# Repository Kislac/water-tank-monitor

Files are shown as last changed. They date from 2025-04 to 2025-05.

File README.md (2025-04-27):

# LiDAR Water Tank Monitor

## Overview

The LiDAR Water Tank Monitor is an ESP32-based (Sunton esp32-2432S032C) project designed to measure and monitor water levels in a tank using a LiDAR sensor. The system integrates with **Home Assistant** via MQTT, providing real-time data on water levels, temperature, and humidity. It features a 3.2-inch capacitive TFT display with LVGL for a user-friendly interface.

The sensor and ESP32 board are connected using an S/FTP Ethernet cable (up to 10 meters), which ensures reliable communication and power delivery over longer distances. This setup helps minimize interference and signal loss, making it suitable for installations where the tank and display/controller are physically separated.

## Table of Contents

- [LiDAR Water Tank Monitor](#lidar-water-tank-monitor)
  - [Overview](#overview)
  - [Table of Contents](#table-of-contents)
  - [Key Features](#key-features)
    - [Main Features](#main-features)
    - [Home Assistant Integration Example](#home-assistant-integration-example)
    - [Hardware](#hardware)
    - [Software](#software)
    - [Customizable Settings](#customizable-settings)
  - [How its Work](#how-its-work)
  - [Development Environment Setup Instructions](#development-environment-setup-instructions)
  - [Pictures](#pictures)
    - [SquareLine Studio Settings](#squareline-studio-settings)
  - [Recommended Wiring Example](#recommended-wiring-example)
  - [Example Circuit](#example-circuit)
  - [T568B Pinout](#t568b-pinout)
  - [Bill of Materials (BOM)](#bill-of-materials-bom)
  - [Sunton esp32-2432S032C Description](#sunton-esp32-2432s032c-description)
  - [Purchase Links](#purchase-links)

## Key Features

### Main Features

- Real-time water level graph visualization
- Temperature and humidity display visualization
- RSSI Visualization
- **WiFi Management:** Scan/connect, display signal strength
- **Backlight Control:** Manual/automatic brightness
- **NTP Time Sync:** Synchronize with NTP servers
- **EEPROM Storage:** MQTT credentials, tank parameters, Wifi
- **MQTT Discovery:** Auto-publish sensor data to Home Assistant
  - Distance (mm)
  - Humidity (%)
  - Liter (L)
  - TankLevelTankLevel (%)
  - Temperature (°C)
- **Misc:**:
  - Dark Mode
  - Languge settings
  - Rotate Screen horizontaly (180°)
  - SW reset Button
  - Runtime Calc
  - FW update Over the AIR

  ### Home Assistant Integration Example

  <p align="center">
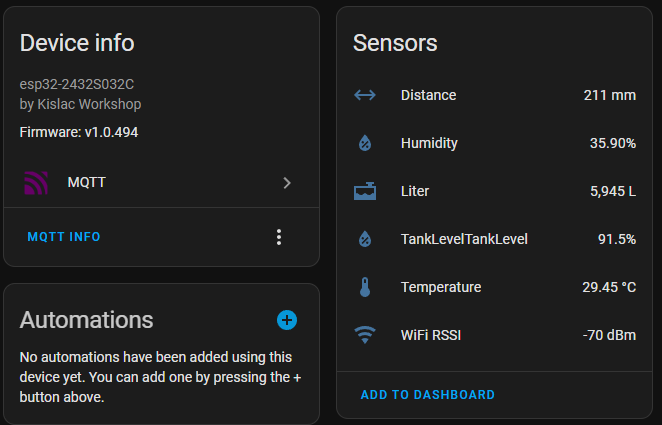
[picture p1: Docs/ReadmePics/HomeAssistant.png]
Home Assistant Integration Example
    
  </p>

### Hardware
- Main HW: Sunton esp32-2432S032C
  - **Microcontroller:** ESP32-D0WDQ6 (Dual-core, 240 MHz, 4 MB SPI Flash)
  - **Display:** 3.2-inch TFT LCD (320x240, 65K colors)
  - **Touchscreen:** GT911 capacitive touch controller (I2C)
  - **Audio:** PWM audio output with built-in amplifier
  - **Connectivity:** WiFi 802.11 b/g/n, Bluetooth v4.2 + BLE
  - **Power Supply:** 5V via USB Type-C, built-in LiPo charging IC
  - **GPIO:** Limited (many pins used for peripherals)
  - **LED:** RGB Led
  - **LightSensor:** used for auto backlight
- **Sensors:**
  - **LiDAR**: TOF400C-VL53L1X
  - **Temperature & Humidity**: AHT10

### Software

- **Framework:** VSCode: Arduino with PlatformIO
- **Libdeps**: 
	- https://github.com/rzeldent/esp32-smartdisplay
	- lvgl/lvgl@^9.2.2
	- knolleary/PubSubClient@^2.8
	- adafruit/Adafruit AHTX0@^2.0.5
	- pololu/VL53L1X@^1.3.1
	- bblanchon/ArduinoJson@^7.4.1
- **UI Library:** LVGL (v9.1.0)
- **Integration:** MQTT for Home Assistant
- **OTA Updates:** Firmware updates via HTTPS
- **PCB Design:** Sprint Layout 6.0
- **CNC File Preparation:** FlatCam
- **PCB Engraving:** UGS 2.1.13 (Universal Gcode Sender)
- **MQTT Testing:** MQTT Explorer 0.4

### Customizable Settings

- Tank type (cylinder or rectangle)
- Tank dimensions and calibration

---

## How its Work

>The system uses a distance sensor mounted above the water tank. The sensor continuously measures the distance from itself to the water surface. Using the tank's dimensions (such as height and diameter), the software calculates the current water level and the total volume of water remaining in the tank. This information is displayed in real time on the screen. Additionally, the system sends water level data via MQTT to Home Assistant for remote monitoring and automation.
---
<p align="center">
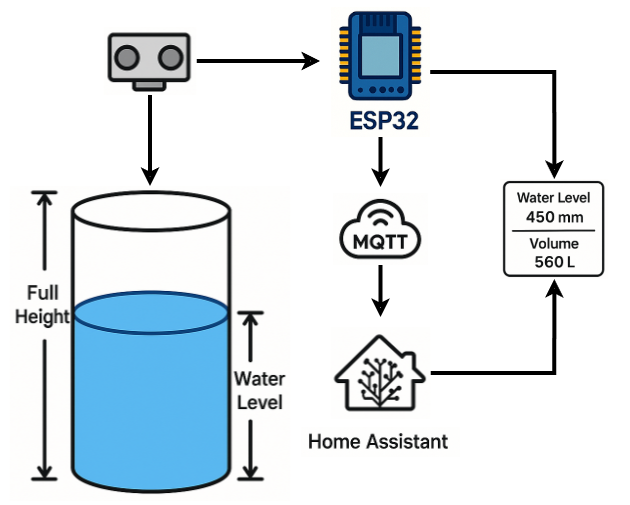
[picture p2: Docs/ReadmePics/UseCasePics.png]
    
  </p>

## Development Environment Setup Instructions
*Only need if you wold like to modify something

1. **Follow these steps:**  
  [https://github.com/rzeldent/esp32-smartdisplay](https://github.com/rzeldent/esp32-smartdisplay)

2. **Install SquareLine Studio:**  
  Version: `SquareLine_Studio_Windows_v1_4_2`

3. **Clone the PlatformIO board definitions:**  
  - Repository: [https://github.com/rzeldent/platformio-espressif32-sunton](https://github.com/rzeldent/platformio-espressif32-sunton)
  - Copy the board definitions to:  
    `<home>/.platformio/platforms/espressif32/boards`
  - 
4. **Create new projects**
  - use the `esp32-2432S032C` board and Aurdiono 
  - Copy  `\.pio\libdeps\esp32-2432S032C\lvgl\lv_conf_template.h`  
  to `\include` and rename to `lv_conf.h` and enable it with `#if 1`
- Provide LVGL config path in `pf.ini` with:  
  `-D LV_CONF_PATH="D:\GIT\water-tank-monitor\include\lv_conf.h"`
- Add `lvgl/lvgl@^9.2.2` library to the project

5. **Memory Map update**
LVGL are using too much Dram. So need to modify the Dram mapping
Find this file
`C:\Users\ikl2bp\.platformio\packages\framework-arduinoespressif32\tools\sdk\esp32\ld\memory.ld`:
Update this part to this:
>dram0_0_seg (RW) : org = 0x3FFB0000 + 0xdb5c,<br>
             len = 0x32710 - 0xdb5c

*Explanation:*
- Start address: `0x3FFB0000`
- Offset: `0xdb5c` (56,796 decimal)
- Total length: `0x30000` (196,608 decimal)
- Available memory: `0x30000 - 0xdb5c = 0x224A4` (140,812 decimal)

---
## Pictures

<p align="center">
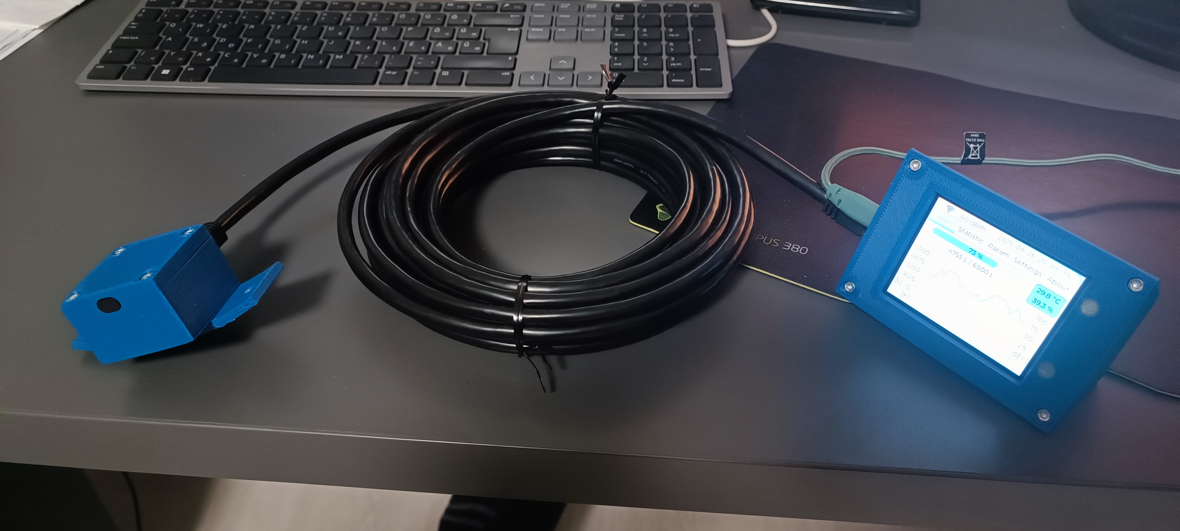
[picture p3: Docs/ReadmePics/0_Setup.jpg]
Device Setup
  
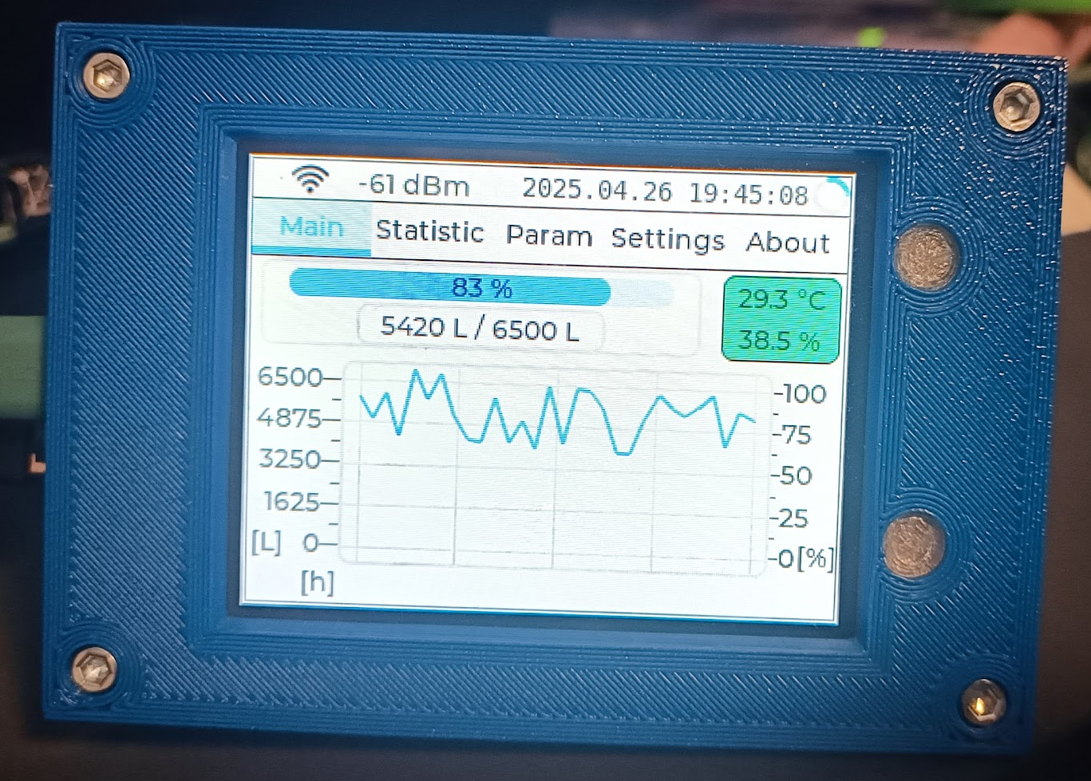
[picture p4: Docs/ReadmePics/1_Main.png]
Main Screen
  
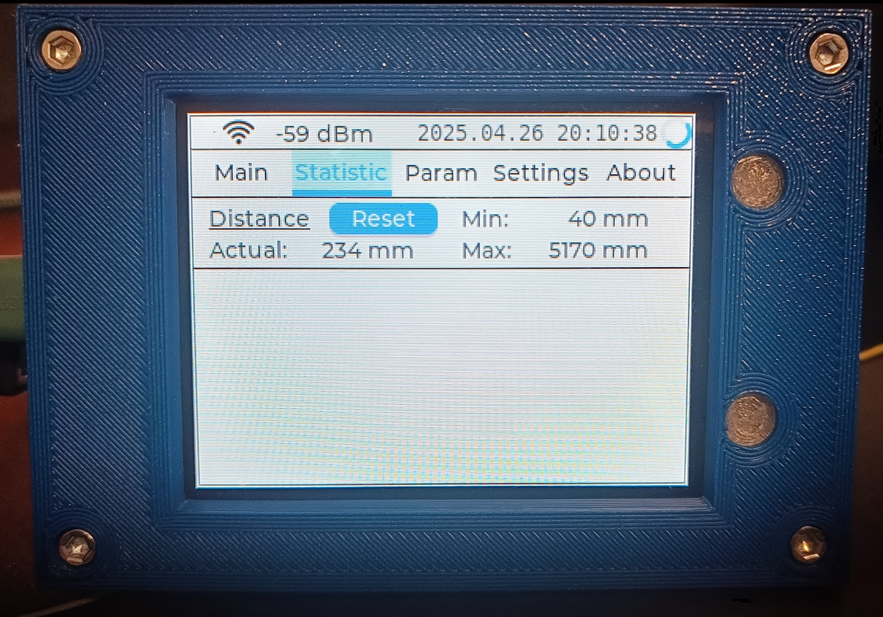
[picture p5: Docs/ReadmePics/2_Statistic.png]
Statistics Screen
  
  Parameter Screen
  Settings Screen
  About Screen
</p>

---

## SquareLine Studio Settings

- **New Project:**
  - Major LVGL version: 9.1
  - Visual Studio for development on Windows PC (v2.0.1)
  - Resolution: 320x240
  - Color Depth: 16 Bit
  - LVGL version: 9.1.0
  - Project Export Root: `D:\GIT\water-tank-monitor`
  - UI Files Export Path: `D:\GIT\water-tank-monitor\src\ui`
  - LVGL Include Path: `lvgl.h`
  - Call functions export file: *do not export*

---

## Recommended Wiring Example

| Pair | Color | Signal |
|---|---|---|
| 1 | Green + Green/White  | SDA + GND |
| 2 | Orange + Orange/White| SCL + GND |
| 3 | Blue + Blue/White | +5V + empty |
| 4 | Brown + Brown/White  | Optional: LED or GPIO |

- Use a lower I2C speed (e.g., 100kHz)
- Use stronger pull-up resistors (e.g., 1.5kΩ instead of 2.2kΩ)
- According to the I2C specification, pull-up resistors are required on SDA and SCL lines.

| Length | Voltage | Recommended Pull-up |
|---|---|---|
| < 1 m  | 3.3V | 4.7kΩ – 10kΩ |
| 5–6 m  | 3.3V | 2.2kΩ – 3.3kΩ |

---

## Example Circuit

```text
ESP32
  ├── SDA ---[2.2kΩ]---+--- SDA wire ---> VL53L1X & AHT10
  │                   |
  │                  3.3V
  └── SCL ---[2.2kΩ]---+--- SCL wire ---> VL53L1X & AHT10

VL53L1X & AHT10
  └── 3.3V ---||--- GND (100nF + 10µF in parallel)
```

---

## T568B Pinout

1. Orange/White    → GND  
2. Orange          → SCL  
3. Green/White     → GND  
4. Blue            → +5V  
5. Blue/White      → Empty  
6. Green           → SDA  
7. Brown/White     → Empty  
8. Brown           → Empty  

---

## Bill of Materials (BOM)
|Picture|Item|Needed|Price(EUR)|Price (HUF)|AliExpress Link| Hungarian Distributor Link|
|-|-|-|-|-|-|-|
|TOF400C-VL53L1|Sunton<br> esp32-2432S032C|1|20 eur|8500 huf|[AliExpress](https://www.aliexpress.com/item/1005008599170226.html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"order"%3A"2"%2C"eval"%3A"1"%7D&pdp_npi=4%40dis%21HUF%218710.51%218276.09%21%21%2123.66%2122.48%21%402103917f17456769168285149e6771%2112000045892717254%21sea%21HU%21165456939%21X&curPageLogUid=LtDidy4eRF31&utparam-url=scene%3Asearch%7Cquery_from%3A)|[Tavir](https://shop.tavir.hu/termek/kiegeszitok/kommunikacio/esp32-lvgl-development-board-3-2-lvgl-touch-esp32-2432s032c/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)|
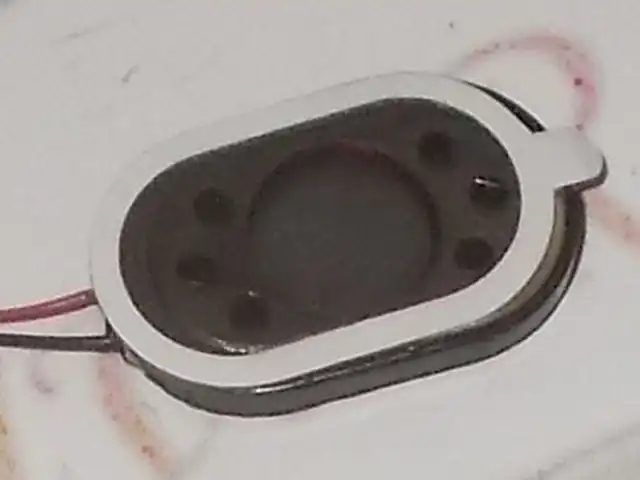
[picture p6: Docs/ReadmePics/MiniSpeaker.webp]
||MiniSpeaker <br>(8R 1W)<br> (Optionally)|1|1 eur|400 huf|[AliExpress](https://www.aliexpress.com/item/1005006116555207.html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"order"%3A"178"%2C"eval"%3A"1"%7D&pdp_npi=4%40dis%21HUF%21921.25%21792.09%21%21%2118.26%2115.70%21%4021038e6617456773259747782e78fa%2112000035824265950%21sea%21HU%21165456939%21X&curPageLogUid=WIlYI5tJOtuN&utparam-url=scene%3Asearch%7Cquery_from%3A)|[Tavir](https://shop.tavir.hu/termek/modulok/hangkeltes-mp3-erosito/mini-hangszoro-8r-1w/)|
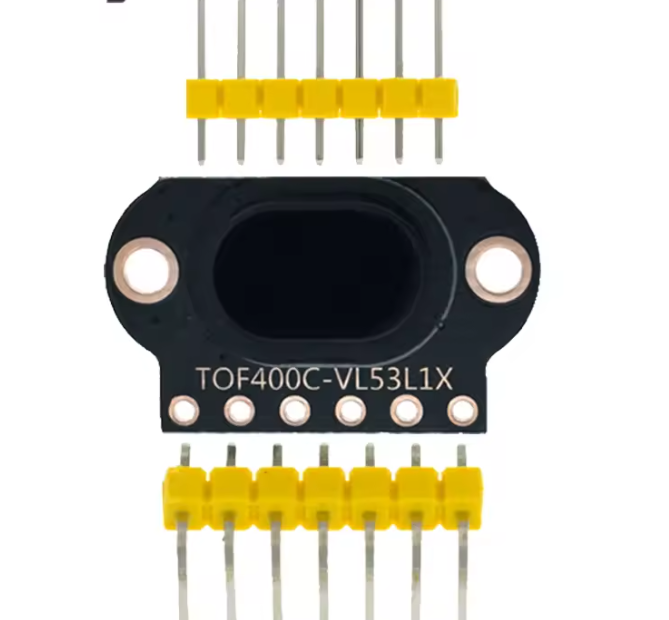
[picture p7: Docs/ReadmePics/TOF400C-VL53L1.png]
||TOF400C-VL53L1|1 pcs|5 eur|2000 huf| [AliExpress](https://www.aliexpress.com/item/1005006160743016.html?spm=a2g0o.order_list.order_list_main.10.6d311802U5VZOT)| [Hestore](https://www.hestore.hu/prod_10041187.html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)|
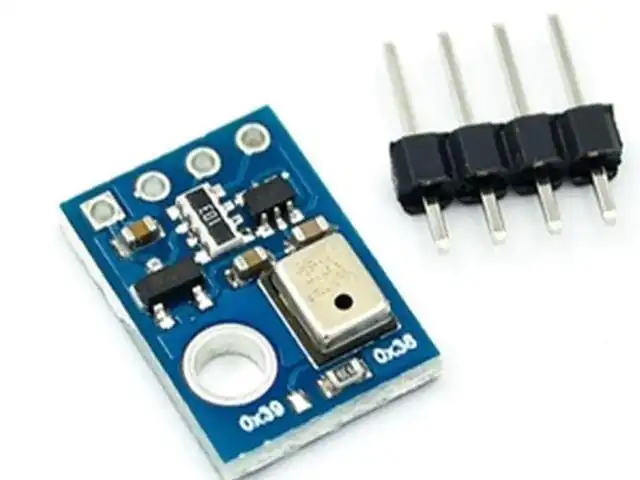
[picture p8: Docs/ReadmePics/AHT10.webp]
||AHT10|1 pcs|2.5 eur|1000 huf|[AliExpress](https://www.aliexpress.com/item/1005005023375532.html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)|[Tavir](https://shop.tavir.hu/termek/modulok/homerseklet/aht10-ho-paraszenzor/)|
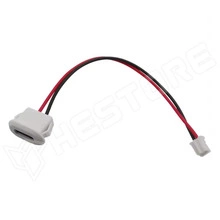
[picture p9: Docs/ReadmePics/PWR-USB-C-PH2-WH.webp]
||PWR-USB-C-PH2-WH|1pcs|? eur|? huf|-|[Hestore](https://www.hestore.hu/prod_10047569.html)|
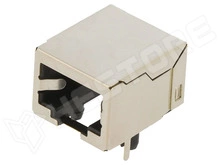
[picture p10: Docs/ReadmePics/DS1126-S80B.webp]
DS1126-S80B
||DS1126-S80B <br>(or similiar)|2pcs|1 Eur|400 Huf|-|[Hestore](https://www.hestore.hu/prod_10041015.html)|
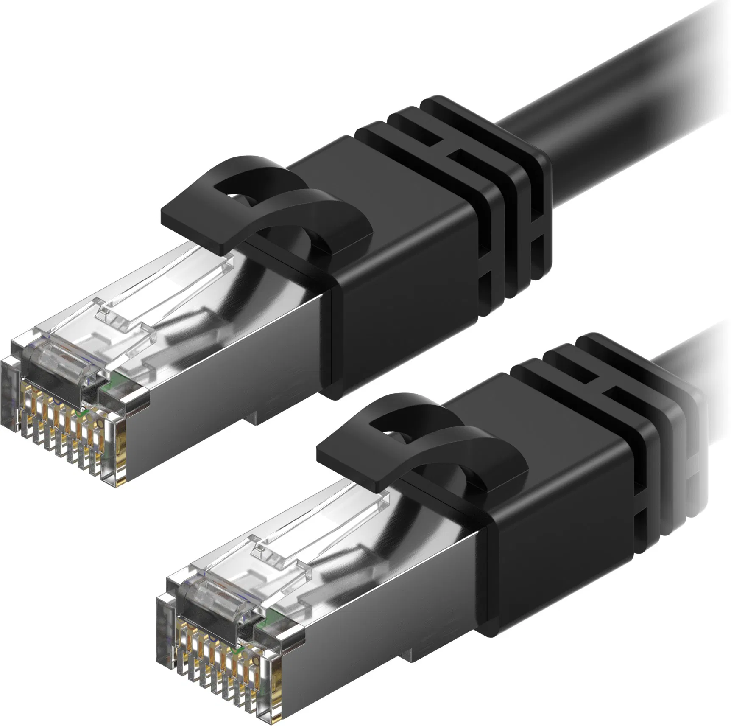
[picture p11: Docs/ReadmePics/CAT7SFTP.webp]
||S/FTP|1pcs|14 Eur|5500 Huf|-|[Alza](https://www.alza.hu/alzapower-patch-cat7-s-ftp-30m-sedy?dq=12481409)|
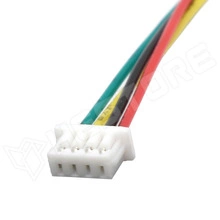
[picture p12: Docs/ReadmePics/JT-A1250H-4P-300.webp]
JT-A1250H-4P-300
||JT-A1250H-4P-300|2pcs|1 eur|500 Huf|-|[Hestore](https://www.hestore.hu/prod_10047751.html)|
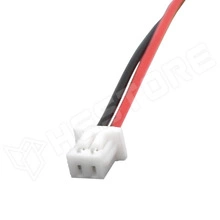
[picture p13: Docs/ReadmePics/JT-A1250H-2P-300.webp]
JT-A1250H-2P-300
||JT-A1250H-4P-300|2pcs|1 eur|500 Huf|-|[Hestore](https://www.hestore.hu/prod_10047749.html)|
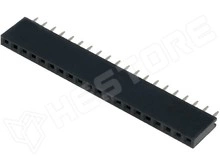
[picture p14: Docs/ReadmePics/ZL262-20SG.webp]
ZL262-20SG
||ZL262-20SG|2 pcs|1 eur|400 Huf|-|[Hestore](https://www.hestore.hu/prod_10028051.html)|
|Total|-|-|~47 Eur|~19200 Huf||-|

---

## Sunton esp32-2432S032C Description

## Purchase Links

- **OEM Product Page:**  
  [displaysmodule.com - 3.2" Capacitive TFT Display Module (240x320, ESP32, LVGL, SPI)](https://www.displaysmodule.com/sale-36526879-capacitive-3-2-inch-tft-display-module-240x320-esp32-lvgl-spi-lcd-module.html)

- **Sunton Official AliExpress Store:**  
  [AliExpress Store #1102010846](https://www.aliexpress.com/store/1102010846)

- **Example AliExpress Listing:**  
  [ESP32-2432S032C Board - AliExpress](https://www.aliexpress.com/item/1005007053922331.html)

- **Hungarian Distributor:**  
  [Tavir.hu - ESP32 LVGL Development Board 3.2"](https://shop.tavir.hu/termek/kiegeszitok/kommunikacio/esp32-lvgl-development-board-3-2-lvgl-touch-esp32-2432s032c/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)

**Main Features:**

- **Microcontroller:**  
  ESP32-D0WDQ6 (Dual-core, 240 MHz)

- **RAM:**  
  520 KB internal SRAM  
  *No separate PSRAM on this board*

- **ROM:**  
  448 KB

- **Flash Memory:**  
  4 MB SPI Flash (for programming and data storage)

- **Display:**  
  3.2 inch, 320x240 pixel, 65K color, TFT-LCD  
  ST7789 controller (SPI interface)  
  GT911 capacitive touch controller (I2C interface)

- **Touchscreen Connection:**  
  I2C bus (default: IO32 - SDA, IO33 - SCL)

- **Audio:**  
  PWM audio output: GPIO26 (amplified, via PicoBlade connector)  
  Built-in amplifier

- **Other Peripherals:**  
  RGB LED  
  Light sensor (generally not functional)  
  SD card slot (SPI)

- **Communication:**  
  WiFi 802.11 b/g/n  
  Bluetooth v4.2 + BLE

- **Power Supply:**  
  5V via USB (Type-C)  
  Built-in LiPo battery charging IC (*does not support deep sleep!*)

- **GPIO Connectors:**  
  Limited availability, as many pins are fixed for display, touch panel, audio output, etc.

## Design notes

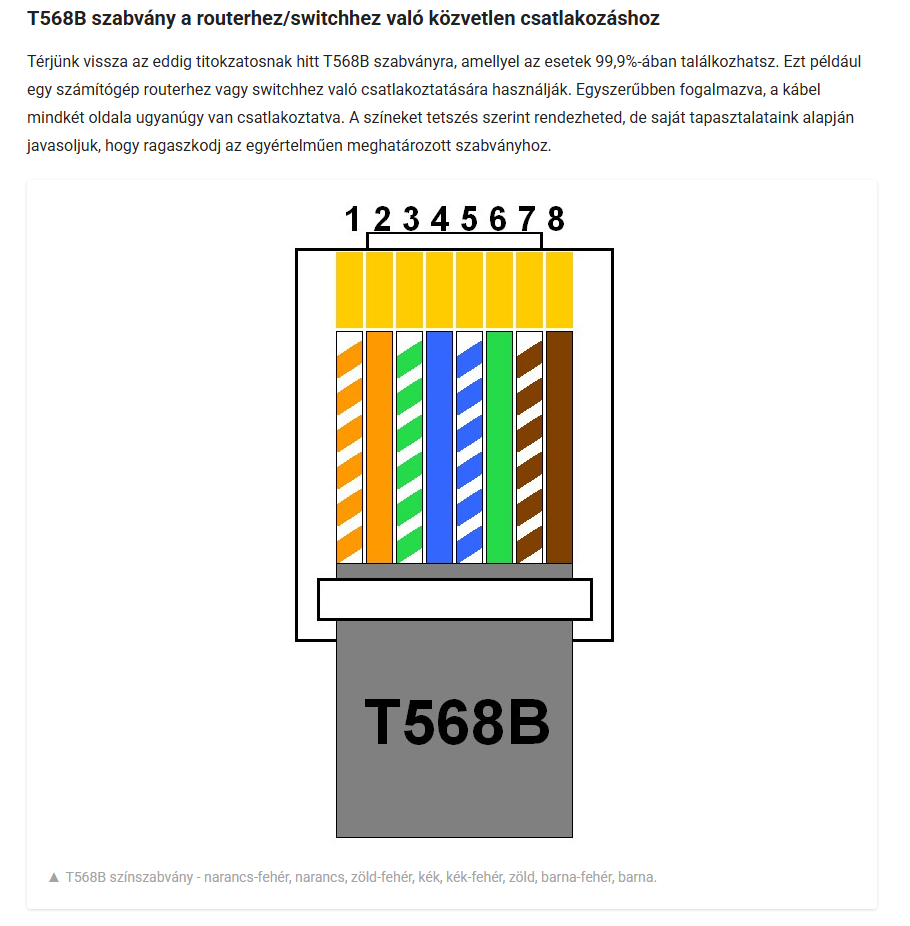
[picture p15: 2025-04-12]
Docs/2025-04-12_16h45_10.png

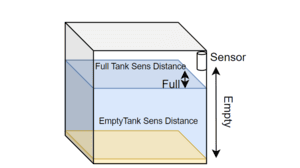
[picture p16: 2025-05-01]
Docs/Resized/4_TankFullEmpty.png

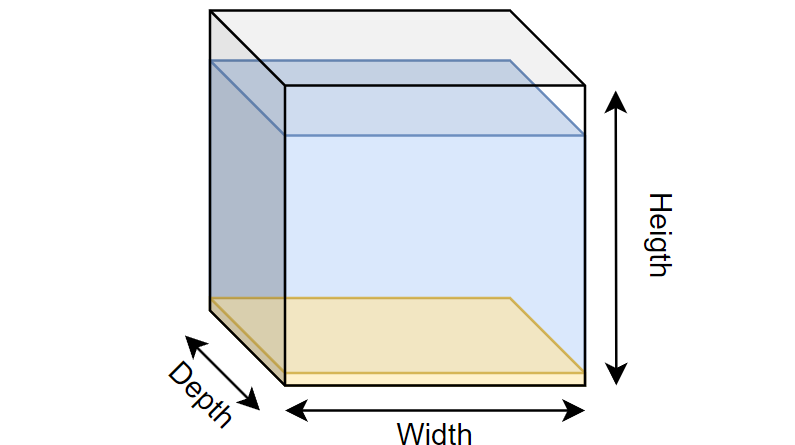
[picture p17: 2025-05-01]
Docs/2_ReactangleDimensions.png

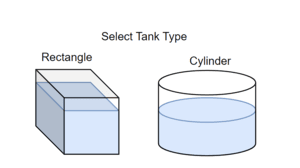
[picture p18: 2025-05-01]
SquareLine/assets/1_SelectTankType.png

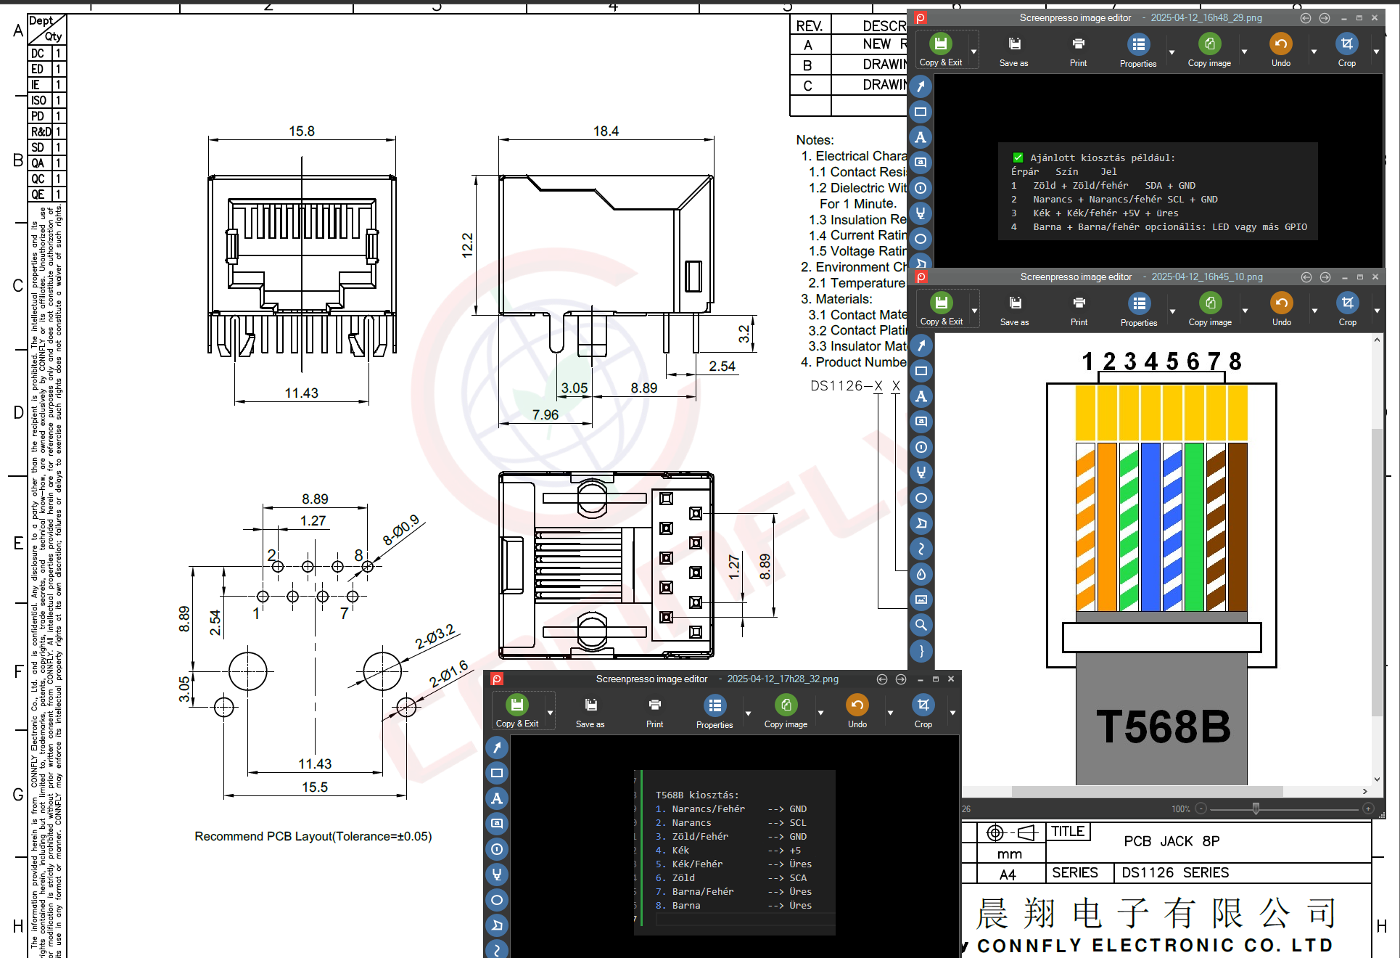
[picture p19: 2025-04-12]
Docs/2025-04-12_17h29_19.png

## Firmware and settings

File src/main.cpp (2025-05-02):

#include "globals.h"
#include <Arduino.h>
#include <esp32_smartdisplay.h>
#include <ui/ui.h>
#include <WiFi.h>
#include <FS.h>     // Include the SPIFFS library for Version handling
#include <SPIFFS.h> // Include the SPIFFS library for Version handling
#include <PubSubClient.h>
#include <EEPROM.h>
//#include <esp_heap_caps.h>

//include OTA
#include <HTTPClient.h>
#include <ArduinoJson.h>
#include <HTTPUpdate.h>



//-------------------------------
#include <Wire.h>
#include <Adafruit_AHTX0.h>
// Define I2C pins for AHT10 (IO21 for SDA, IO22 for SCL)
#define AHT10_SDA 21
#define AHT10_SCL 22

// Define I2C pins for VL53L1X (IO21 for SDA, IO22 for SCL)
#define VL53L1X_SDA 21
#define VL53L1X_SCL 22

// Create a TwoWire object for I2C_NUM_1
TwoWire I2C_AHT10 = TwoWire(1);  // Specify the I2C peripheral (1 for I2C_NUM_1)

Adafruit_AHTX0 aht = Adafruit_AHTX0();  // Create the sensor object
float Temperature_Value = 0;
float Huminidity_Value = 0;


TwoWire I2C_VL53L1X = TwoWire(1);  // Specify the I2C peripheral (1 for I2C_NUM_1)
#include <VL53L1X.h>
VL53L1X sensor;// = VL53L1X();
// Define arrays to store temperature and humidity data
float temp_data[10] = {0};
float hum_data[10] = {0};
int data_index = 0;
//------------------------
bool lvgl_enabled = true;

bool vl53l1x_initialized = false;
bool aht10_initialized = false;


//Set the screen brightness to 50% initially
#define SCREEN_INITIAL_BRIGHTNESS 50
ulong next_millis;
auto lv_last_tick = millis();
char text_buffer[32];

int64_t now = 0;
String security;

bool internetOK = false;
bool wifiConnected = false;
char macAddress[18];
char device_name[32];
char device_identifiers[32];
char device_manufacturer[32];
char device_model[32];
char device_sw_version[32];

WiFiClient espClient;
PubSubClient client(espClient);
bool MQTT_Configured = false;

char global_mqtt_server[64];
char global_mqtt_user[64];
char global_mqtt_password[64];

bool FW_Update_Check = false;


int global_minDistance = INT_MAX; // Initialize to maximum possible value
int global_maxDistance = INT_MIN; // Initialize to minimum possible value

int build_number = 0;

uint8_t global_tankType = 0;
uint16_t global_rectWide = 0;
uint16_t global_rectDepth = 0;
uint16_t global_rectHeight = 0;
uint16_t global_cilDiameter = 0;
uint16_t global_cilHeight = 0;
uint16_t global_emptyTank = 0;
uint16_t global_fullTank = 0;
float global_MaxTankLevelInLiter = 0;
float global_tankVolume = 0.0f;

int distance = 0;
int CurrentLiter;
float CurrentLiterInPer;

// Inicializáld a globális változót
//lv_obj_t * global_ui_Info = NULL;

void initializeBuildInfo()
{
  
  // Get and print the build date and time
  Serial.printf("Build Date: %s, Build Time: %s\n", __DATE__, __TIME__);

  // Update the ui_BuildDateValue with the build date and time
  lv_label_set_text_fmt(ui_lblBuildDateValue, "%s %s", __DATE__, __TIME__);
  
  // Read the build number from version.txt
  if (!SPIFFS.begin(true)) {
    Serial.println("An Error has occurred while mounting SPIFFS");
    return;
  }

  File versionFile = SPIFFS.open("/version.txt", "r");
  if (!versionFile) {
    Serial.println("Failed to open version file");
    return;
  }

  build_number = versionFile.parseInt();
  Serial.printf("Build_number: %d \n", build_number);
  versionFile.close();

  // Update the ui_VerValue with the code version
  device_sw_version[16];
  sprintf(device_sw_version, "v1.1.%d", build_number);
  lv_label_set_text(ui_lblBuildVersionValue, device_sw_version);
}


lv_obj_t * WifiInternetOKImages[1];
lv_obj_t * WifiDisconnectedImages[1];
lv_obj_t * WifiConnectedNoInternetImages[1];
void initWifiSignalImages(){
  WifiInternetOKImages[0] = ui_imWifiInternetOK1;
  //WifiInternetOKImages[1] = ui_imWifiInternetOK2;
  //WifiInternetOKImages[2] = ui_imWifiInternetOK3;
  //WifiInternetOKImages[3] = ui_imWifiInternetOK4;
  //WifiInternetOKImages[4] = ui_imWifiInternetOK5;
  WifiDisconnectedImages[0] = ui_imWifiDisconnected1;
  //WifiDisconnectedImages[1] = ui_imWifiDisconnected2;
  //WifiDisconnectedImages[2] = ui_imWifiDisconnected3;
  //WifiDisconnectedImages[3] = ui_imWifiDisconnected4;
  //WifiDisconnectedImages[4] = ui_imWifiDisconnected5;
  WifiConnectedNoInternetImages[0] = ui_imWifiConnectedNoInternet1;
  //WifiConnectedNoInternetImages[1] = ui_imWifiConnectedNoInternet2;
  //WifiConnectedNoInternetImages[2] = ui_imWifiConnectedNoInternet3;
  //WifiConnectedNoInternetImages[3] = ui_imWifiConnectedNoInternet4;
  //WifiConnectedNoInternetImages[4] = ui_imWifiConnectedNoInternet5;
}


// Függvény a képek láthatóságának frissítésére
void updateStatusImages(bool internetOK) {
  // WiFi Disconnected képek kezelése

  int wifiDisconnectedImagesCount = sizeof(WifiInternetOKImages) / sizeof(WifiInternetOKImages[0]);
  //Serial.printf("wifiDisconnectedImages has %d elements\n", wifiDisconnectedImagesCount);
  for (int i = 0; i < wifiDisconnectedImagesCount; i++) {
    if (WifiInternetOKImages[i] == nullptr) {
      Serial.printf("wifiDisconnectedImages[%d] is nullptr\n", i);
    } else {
      //lv_obj_t* img = wifiDisconnectedImages[i];
      //if (img != nullptr) { // Ensure the pointer is not null
          if (wifiConnected && internetOK) {
              lv_obj_add_flag(WifiDisconnectedImages[i], LV_OBJ_FLAG_HIDDEN); // Elrejtés
              lv_obj_add_flag(WifiConnectedNoInternetImages[i], LV_OBJ_FLAG_HIDDEN); // Elrejtés
              lv_obj_clear_flag(WifiInternetOKImages[i], LV_OBJ_FLAG_HIDDEN); // Megjelenítés
          } else if (wifiConnected && !internetOK) {
              lv_obj_add_flag(WifiDisconnectedImages[i], LV_OBJ_FLAG_HIDDEN); // Elrejtés
              lv_obj_clear_flag(WifiConnectedNoInternetImages[i], LV_OBJ_FLAG_HIDDEN); // Megjelenítés
              lv_obj_add_flag(WifiInternetOKImages[i], LV_OBJ_FLAG_HIDDEN); // Elrejtés
          } else if (!wifiConnected){
              lv_obj_clear_flag(WifiDisconnectedImages[i], LV_OBJ_FLAG_HIDDEN); // Megjelenítés
              lv_obj_add_flag(WifiConnectedNoInternetImages[i], LV_OBJ_FLAG_HIDDEN); // Elrejtés
              lv_obj_add_flag(WifiInternetOKImages[i], LV_OBJ_FLAG_HIDDEN); // Elrejtés
          }  
    }
  }

}

// Hívás a státusz frissítésére
void CheckWifiandInternetStatus() {
    static ulong last_status_refresh_time = 0;

    if (millis() - last_status_refresh_time >= 1000) { // Refresh every second
      last_status_refresh_time = millis();

      wifiConnected = (WiFi.status() == WL_CONNECTED);
      internetOK = false;

      // Internet kapcsolat ellenőrzése
      WiFiClient client;
      if (wifiConnected && client.connect("www.google.com", 80)) {
        internetOK = true;
        client.stop();
      }

      // Frissítsd a képeket
      updateStatusImages(internetOK);
    }
}

void RefreshWifiParameters() {
  static ulong last_refresh_time = 0;

  if (millis() - last_refresh_time >= 5000) { // Refresh every 5 seconds
    last_refresh_time = millis();

    if(lv_scr_act() == ui_Wifi_Settings){
      // Refresh WiFi status
      const char *status = (WiFi.status() == WL_CONNECTED) ? "Connected" : "Disconnected";
      lv_label_set_text(ui_lblWifiStatus, status);


      if (WiFi.status() == WL_CONNECTED) {
        // Refresh SSID
        lv_label_set_text(ui_lblWifiSSID, WiFi.SSID().c_str());
        

        // Refresh IP address
        lv_label_set_text(ui_lblWifiIP, WiFi.localIP().toString().c_str());

        // Refresh RSSI
        char rssi_text[16];
        snprintf(rssi_text, sizeof(rssi_text), "%d dBm", WiFi.RSSI());
        lv_label_set_text(ui_lblWifiRSSI, rssi_text);
        //lv_label_set_text(ui_lblWifiRSSI2, rssi_text);

        // Refresh Channel
        char channel_text[16];
        snprintf(channel_text, sizeof(channel_text), "Ch: %d", WiFi.channel());
        lv_label_set_text(ui_lblWifiChannel, channel_text);

        lv_label_set_text(ui_lblWifiSecurity, security.c_str());

        
        
      } else {
        // Clear labels if not connected
        lv_label_set_text(ui_lblWifiSSID, "N/A");
        lv_label_set_text(ui_lblWifiRSSI2, "N/A");
        lv_label_set_text(ui_lblWifiIP, "N/A");
        lv_label_set_text(ui_lblWifiRSSI, "N/A");
        lv_label_set_text(ui_lblWifiChannel, "N/A");
        lv_label_set_text(ui_lblWifiSecurity, "N/A");
      }
    }else if(lv_scr_act() == ui_Main_Screen){
      if (WiFi.status() == WL_CONNECTED) {
        // Refresh RSSI
        char rssi_text[16];
        snprintf(rssi_text, sizeof(rssi_text), "%d dBm", WiFi.RSSI());
        lv_label_set_text(ui_lblWifiRSSI2, rssi_text);
      }else{
        lv_label_set_text(ui_lblWifiRSSI2, "- dBm");
      }
    }
  }
}

void runtimecalc(){
  static ulong last_runtime = 0;

  if (millis() - last_runtime >= 100) { // Refresh every 100ms
    last_runtime = millis();

    int64_t total_seconds = now / 1000;
    int years = total_seconds / (365 * 24 * 3600);
    total_seconds %= (365 * 24 * 3600);
    int days = total_seconds / (24 * 3600);
    total_seconds %= (24 * 3600);
    int hours = total_seconds / 3600;
    total_seconds %= 3600;
    int minutes = total_seconds / 60;
    float seconds = total_seconds % 60 + (now % 1000) / 1000.0;

    if (lv_tabview_get_tab_act(ui_MainTabView) == 4) {
        // Update the audio tab
        sprintf(text_buffer, "%02d-%03d %02d:%02d:%02.1f", years, days, hours, minutes, seconds);
        lv_label_set_text(ui_lblRunTimeValue, text_buffer);
        //sprintf(text_buffer, "%02d hour %02d min %02.1f sec", hours, minutes, seconds);
        //lv_label_set_text(ui_lblRuntimeHMSValue, text_buffer);
    }
  }
}

void DateAndTimeHandling(){
static ulong last_ntp_sync = 0;
static ulong last_time_update = 0;
static time_t current_time = 0; // Store the current time in seconds since epoch
//static int timezone_offset = 3600; // Default timezone offset in seconds (CET)

if (internetOK && (millis() - last_ntp_sync >= 60000*5 || current_time < 946684800)) { // Sync with NTP every 60 seconds or before year 2000
  configTzTime("CET-1CEST,M3.5.0/2,M10.5.0/3", "pool.ntp.org", "time.nist.gov"); // Configure NTP servers
  struct tm timeinfo;
  if (getLocalTime(&timeinfo)) {
    current_time = mktime(&timeinfo); // Update current time
    last_ntp_sync = millis();
    Serial.println("Time synchronized with NTP.");
  } else {
    Serial.println("Failed to synchronize time with NTP.");
  }
}

if (millis() - last_time_update >= 1000) { // Update time every second
  last_time_update = millis();
  current_time++; // Increment the current time by one second
  //Serial.printf("Current time: %d", current_time); // Print the current time
  struct tm *timeinfo = localtime(&current_time);
  if (timeinfo) {
    char datetime_text[32];
    strftime(datetime_text, sizeof(datetime_text), "%Y.%m.%d %H:%M:%S", timeinfo);
    //lv_label_set_text(ui_lblTime, datetime_text);
    lv_label_set_text(ui_lblDataNTime, datetime_text);

  } else {
    //lv_label_set_text(ui_lblTime, "Time Unavailable");
    lv_label_set_text(ui_lblDataNTime, "Time Unavailable");
  }
}
  
}

void AutoBacklight(){
  #ifdef BOARD_HAS_CDS
  static ulong last_AutoBacklight = 0;
  static int last_slider_value = 0;

  if (millis() - last_AutoBacklight >= 100) { // Refresh every 100ms
    // Debounced EEPROM save for slider value
    static ulong last_slider_change_time = 0;
    static bool slider_changed = false;

    last_AutoBacklight = millis();
    auto cdr = analogReadMilliVolts(CDS);
    sprintf(text_buffer, "%d", cdr);
    if (lv_tabview_get_tab_act(ui_MainTabView) == 3) {
        lv_label_set_text(ui_lblLigthSensorValue, text_buffer);
    }
    
    if (lv_obj_get_state(ui_switchManualAutomatic) & LV_STATE_CHECKED) {
        float adaptive_brightness = smartdisplay_lcd_adaptive_brightness_cds();
        smartdisplay_lcd_set_backlight(adaptive_brightness);
        if (lv_tabview_get_tab_act(ui_MainTabView) == 3) {
          int slider_value = (int)(adaptive_brightness * 100);
          lv_slider_set_value(ui_LigthSensorSlider, slider_value, LV_ANIM_OFF);
          sprintf(text_buffer, "%d%%", slider_value);
          lv_label_set_text(ui_lblLigthSensorSliderValue, text_buffer);
        }
    }
    int slider_value = lv_slider_get_value(ui_LigthSensorSlider);
    if (!(lv_obj_get_state(ui_switchManualAutomatic) & LV_STATE_CHECKED) && slider_value != last_slider_value) {
        // Read the slider value
        
        
        //int slider_value = lv_slider_get_value(ui_LigthSensorSlider);
        float lcd_set_backlight = (float)slider_value / 100;
        Serial.printf("slider_value: %d | lcd_set_backlight: %.2f\n", slider_value, lcd_set_backlight);
        smartdisplay_lcd_set_backlight(max(lcd_set_backlight, 0.01f));

        // Detect slider value change
        if (slider_value != last_slider_value) {
          last_slider_change_time = millis();
          slider_changed = true;
          last_slider_value = slider_value;
        }


    }
    // Save to EEPROM if 3 seconds have passed since last change
    if (slider_changed && (millis() - last_slider_change_time >= 3000)) {
      EEPROM.begin(512);
      EEPROM.write(301, slider_value); // Store slider value at address 301
      EEPROM.commit();
      EEPROM.end();
      Serial.printf("Light sensor slider value saved (delayed): %d\n", slider_value);
      slider_changed = false;
    }

  }
  #endif
}


void publishDiscoveryMessages() {
  if (!client.connected()) return;  // Ne próbáljunk publish-olni, ha nincs kapcsolat

  Serial.println("Publishing discovery...");
  if (!client.connected()) {
    Serial.println("MQTT client is not connected.");
    return;
  }

  if (WiFi.status() != WL_CONNECTED) {
      Serial.println("WiFi is not connected.");
      return;
  }



  char rssi_discovery_topic[128];
  snprintf(rssi_discovery_topic, sizeof(rssi_discovery_topic), "homeassistant/sensor/%s_wifi_rssi/config", macAddress);
  char rssi_discovery_payload[512];
  snprintf(rssi_discovery_payload, sizeof(rssi_discovery_payload),
  "{"
    "\"name\":\"WiFi RSSI\","
    "\"uniq_id\":\"WTM_wifi_rssi_%s\","
    "\"state_topic\":\"WTM_%s/wifi/rssi\","
    "\"unit_of_measurement\":\"dBm\","
    "\"device_class\":\"signal_strength\","
    "\"device\":{"
      "\"name\":\"%s\","
      "\"identifiers\":[\"%s\"],"
      "\"manufacturer\":\"%s\","
      "\"model\":\"%s\","
      "\"sw_version\":\"%s\""
    "}"
  "}", macAddress, macAddress, device_name, device_identifiers,device_manufacturer, device_model, device_sw_version);
  bool result_rssi = client.publish(rssi_discovery_topic, rssi_discovery_payload, false);
  Serial.print("MQTT: RSSI discovery publish result: ");
  Serial.println(result_rssi ? "OK" : "FAILED");
//  if (!result_rssi) {
//    Serial.print("MQTT client state: ");
//    Serial.println(client.state());
//  }

  // Temperature discovery
  char temp_discovery_topic[128];
  snprintf(temp_discovery_topic, sizeof(temp_discovery_topic), "homeassistant/sensor/%s_temperature/config", macAddress);
  char temp_discovery_payload[512];
  snprintf(temp_discovery_payload, sizeof(temp_discovery_payload),
  "{"
    "\"name\":\"Temperature\","
    "\"uniq_id\":\"WTM_temperature_%s\","
    "\"state_topic\":\"WTM_%s/sensor/temperature\","
    "\"unit_of_measurement\":\"°C\","
    "\"device_class\":\"temperature\","
    "\"device\":{"
      "\"name\":\"%s\","
      "\"identifiers\":[\"%s\"],"
      "\"manufacturer\":\"%s\","
      "\"model\":\"%s\","
      "\"sw_version\":\"%s\""
    "}"
  "}", macAddress, macAddress, device_name, device_identifiers, device_manufacturer, device_model, device_sw_version);
  bool result_temp = client.publish(temp_discovery_topic, temp_discovery_payload, true);
  Serial.print("MQTT: Temperature discovery publish result: ");
  Serial.println(result_temp ? "OK" : "FAILED");

  // Humidity discovery
  char hum_discovery_topic[128];
  snprintf(hum_discovery_topic, sizeof(hum_discovery_topic), "homeassistant/sensor/%s_humidity/config", macAddress);
  char hum_discovery_payload[512];
  snprintf(hum_discovery_payload, sizeof(hum_discovery_payload),
  "{"
    "\"name\":\"Humidity\","
    "\"uniq_id\":\"WTM_humidity_%s\","
    "\"state_topic\":\"WTM_%s/sensor/humidity\","
    "\"unit_of_measurement\":\"%%\","
    "\"device_class\":\"humidity\","
    "\"device\":{"
      "\"name\":\"%s\","
      "\"identifiers\":[\"%s\"],"
      "\"manufacturer\":\"%s\","
      "\"model\":\"%s\","
      "\"sw_version\":\"%s\""
    "}"
  "}", macAddress, macAddress, device_name, device_identifiers, device_manufacturer, device_model, device_sw_version);
  bool result_hum = client.publish(hum_discovery_topic, hum_discovery_payload, true);
  Serial.print("MQTT: Humidity discovery publish result: ");
  Serial.println(result_hum ? "OK" : "FAILED");

  // Distance discovery
  char distance_discovery_topic[128];
  snprintf(distance_discovery_topic, sizeof(distance_discovery_topic), "homeassistant/sensor/%s_distance/config", macAddress);
  char distance_discovery_payload[512];
  snprintf(distance_discovery_payload, sizeof(distance_discovery_payload),
  "{"
    "\"name\":\"Distance\","
    "\"uniq_id\":\"WTM_distance_%s\","
    "\"state_topic\":\"WTM_%s/sensor/distance\","
    "\"unit_of_measurement\":\"mm\","
    "\"device_class\":\"distance\","
    "\"device\":{"
      "\"name\":\"%s\","
      "\"identifiers\":[\"%s\"],"
      "\"manufacturer\":\"%s\","
      "\"model\":\"%s\","
      "\"sw_version\":\"%s\""
    "}"
  "}", macAddress, macAddress, device_name, device_identifiers, device_manufacturer, device_model, device_sw_version);
  bool result_dist = client.publish(distance_discovery_topic, distance_discovery_payload, true);
  Serial.print("MQTT: Distance discovery publish result: ");
  Serial.println(result_dist ? "OK" : "FAILED");

  // Liter discovery
  char liter_discovery_topic[128];
  snprintf(liter_discovery_topic, sizeof(liter_discovery_topic), "homeassistant/sensor/%s_liter/config", macAddress);
  char liter_discovery_payload[512];
  snprintf(liter_discovery_payload, sizeof(liter_discovery_payload),
  "{"
    "\"name\":\"Liter\","
    "\"uniq_id\":\"WTM_liter_%s\","
    "\"state_topic\":\"WTM_%s/sensor/liter\","
    "\"unit_of_measurement\":\"L\","
    "\"device_class\":\"volume\","
    "\"device\":{"
      "\"name\":\"%s\","
      "\"identifiers\":[\"%s\"],"
      "\"manufacturer\":\"%s\","
      "\"model\":\"%s\","
      "\"sw_version\":\"%s\""
    "}"
  "}", macAddress, macAddress, device_name, device_identifiers, device_manufacturer, device_model, device_sw_version);
  bool result_Liter = client.publish(liter_discovery_topic, liter_discovery_payload, true);
  Serial.print("MQTT: Liter discovery publish result: ");
  Serial.println(result_Liter ? "OK" : "FAILED");

  // TankLevel discovery
  char TankLevelPercentage_discovery_topic[128];
  snprintf(TankLevelPercentage_discovery_topic, sizeof(TankLevelPercentage_discovery_topic), "homeassistant/sensor/%s_TankLevelpercentage/config", macAddress);
  char TankLevelPercentage_discovery_payload[512];
  snprintf(TankLevelPercentage_discovery_payload, sizeof(TankLevelPercentage_discovery_payload),
  "{"
    "\"name\":\"TankLevelTankLevel\","
    "\"uniq_id\":\"WTM_TankLevelPercentage_%s\","
    "\"state_topic\":\"WTM_%s/sensor/TankLevelpercentage\","
    "\"unit_of_measurement\":\"%%\","
    "\"device_class\":\"moisture\","
    "\"device\":{"
      "\"name\":\"%s\","
      "\"identifiers\":[\"%s\"],"
      "\"manufacturer\":\"%s\","
      "\"model\":\"%s\","
      "\"sw_version\":\"%s\""
    "}"
  "}", macAddress, macAddress, device_name, device_identifiers, device_manufacturer, device_model, device_sw_version);
  bool result_TankLevelPercentage = client.publish(TankLevelPercentage_discovery_topic, TankLevelPercentage_discovery_payload, true);
  Serial.print("TankLevelPercentage discovery publish result: ");
  Serial.println(result_TankLevelPercentage ? "OK" : "FAILED");
}

bool MQTT_Connect() {
  if (client.connect("esp32_water_tank", global_mqtt_user, global_mqtt_password)) {
    Serial.println("MQTT: Connected to the MQTT server!");
    //client.subscribe("esp32/water"); Ez a fogadáshoz kell

    // Discovery topicok küldése
    publishDiscoveryMessages();
    return true;
  } else {
    Serial.print("MQTT: Not able to connect the MQTT server!, error code: ");
    Serial.println(client.state());
    return false;
  }
}

void MQTT_setup(){
  static ulong last_MQTT_Connect = 0;
  if (millis() - last_MQTT_Connect >= 5000) { // Refresh every 100ms
    last_MQTT_Connect = millis();
    if (MQTT_Configured && wifiConnected) {
      client.setServer(global_mqtt_server, 1883);
      client.setBufferSize(1024);
      //client.setCallback(callback);
      while (!client.connected()) {
        Serial.print("Kapcsolódás az MQTT szerverhez: ");
        //Serial.println(mqtt_server);
    
        if (MQTT_Connect()) {
          break;
        } else {
          
            //Serial.print("MQTT: Not able to connect the MQTT server!, error code: ");
            //Serial.print(client.state());
            Serial.println(". retry after 5 sec...");
        }
      }
    }
  }
}
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
void loop() {
  // put your main code here, to run repeatedly:
    now = millis();

    checkFreeHeapMemory();

  if (FW_Update_Check == false && lv_scr_act() == ui_Main_Screen) {
    runtimecalc();
    AutoBacklight();
    RefreshWifiParameters();
    DateAndTimeHandling();
    CheckWifiandInternetStatus();
    check_and_update_graph_value();
    aht10_initialized ? ReadAHT10() : ReinitializeAHT10();
    vl53l1x_initialized ? DistanceSensorRead() : ReinitializeVL53L1X();

    if (!client.connected()) MQTT_setup();
      client.loop();

    publishMQTTSensoraDatas();
  }  
    


    if (lvgl_enabled) {
      // Update the ticker
      lv_tick_inc(now - lv_last_tick);
      lv_last_tick = now;
      // Update the UI
      lv_timer_handler();
    }





}

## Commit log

2025-04-16 Flat Cam Stuff added
    [WaterTankMonitr_PCB_Plan_copper_bottom.gbr, WaterTankMonitr_PCB_Plan_outline.gbr, drill.DRL]
2025-04-26 Readme Updated
    [partitions.csv]
